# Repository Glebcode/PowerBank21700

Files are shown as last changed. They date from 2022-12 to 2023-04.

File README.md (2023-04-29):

# **Chunks PowerBank21700 DIY creation**
.stl for 3d printed power bank and manual for assembling all parts together.

**1.** Printed parts:
 
*-  bottomPartPowerBank21700.*

*-  topLidPartPowerBank21700.*

*-  bracketInsidePartPowerBank21700.*

*-  buttonPowerBank21700.*

**2.** 21700 batteries 6 pcs.

**3.** LED Dual USB 5V 2.4A Micro/Type-C USB Mobile Power Bank Charging Module.

**4.** Nickel stripe ≈ 35-40 cm.

**5.** Wire 22 awg ≈ 30cm.

**6.** Screws M1.6 х 6mm - 4pcs, М3 х 12mm – 4pcs.

**7.** Electrical isolation tape.

*More details, links and information you can find in **word files** in english, hebrew and ukrainian.<br> 
Hope you will enjoy it !*<br>
https://youtu.be/oLE26JI4mzE - short review video.

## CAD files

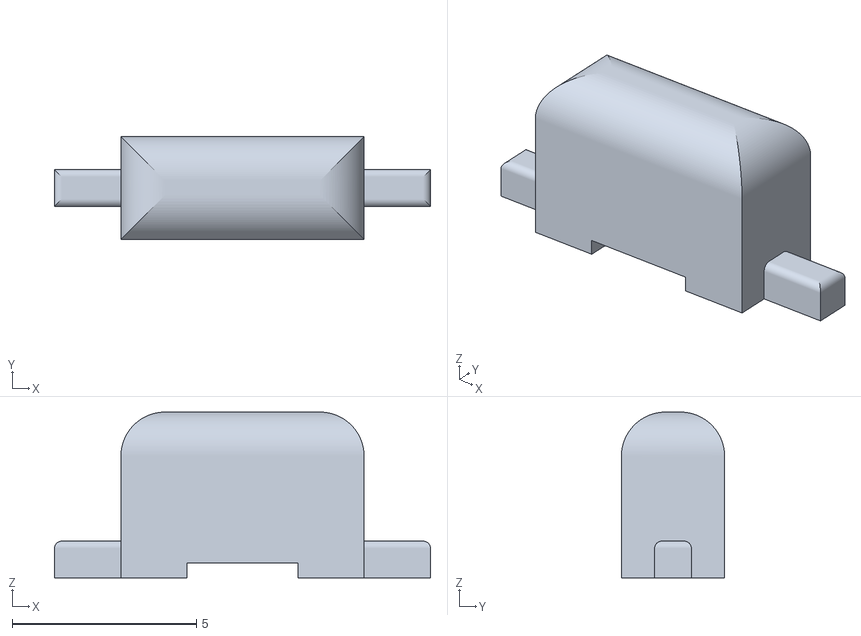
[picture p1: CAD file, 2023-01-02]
buttonPowerBank21700.stl
10.2 x 2.80 x 4.50

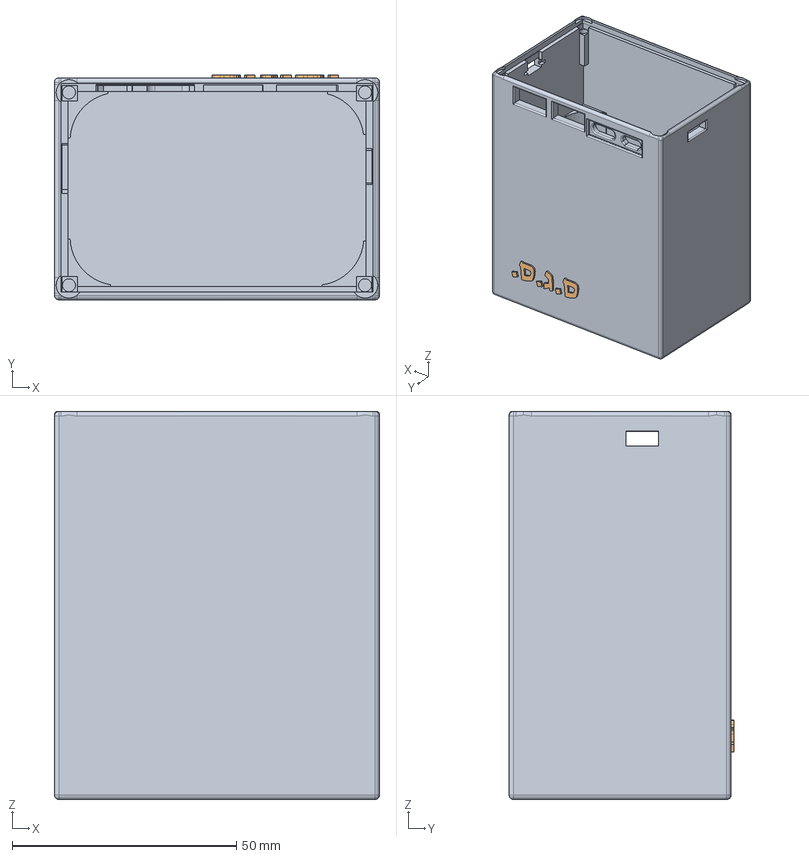
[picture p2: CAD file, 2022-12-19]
powerBank21700.FCStd
72.5 x 50.1 x 86.5 mm
hull
logo

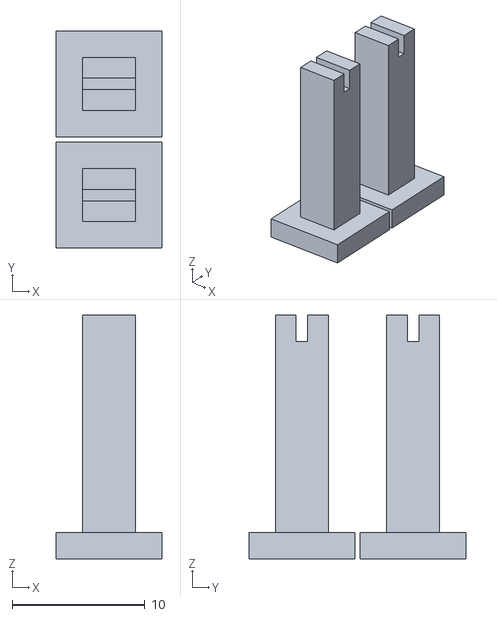
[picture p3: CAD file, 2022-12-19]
bracketInsidePartPowerBank21700.stl
8.00 x 16.4 x 18.4

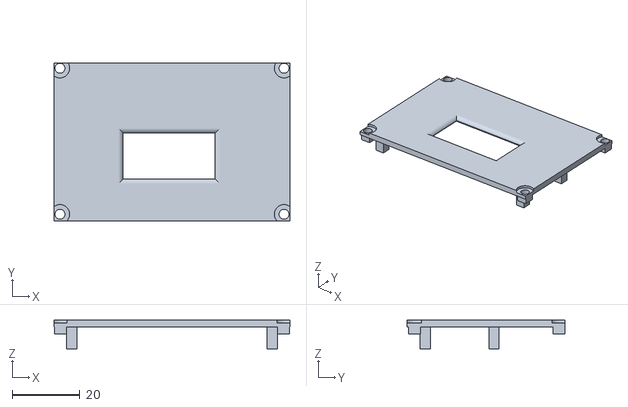
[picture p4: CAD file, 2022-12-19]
topLidPartPowerBank21700.stl
69.5 x 46.5 x 8.40

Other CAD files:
powerBank21700.stl

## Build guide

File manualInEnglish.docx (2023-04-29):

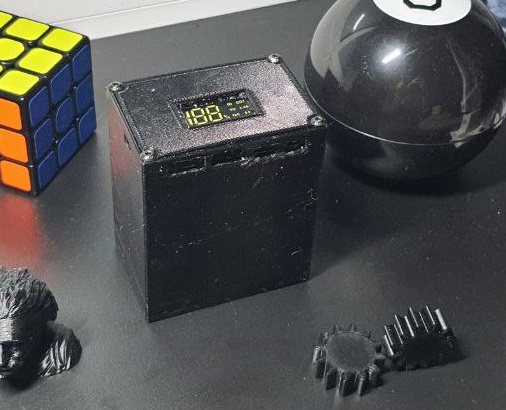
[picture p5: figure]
PB

Instructions how to assemble - Power Bank 6 elements 21700

Parts:

1. Printed parts:

a) bottomPartPowerBank21700.

b) topLidPartPowerBank21700.

c) bracketInsidePartPowerBank21700.

d) buttonPowerBank21700.

2. 21700 (any of), it is desirable to find 5000mAh.

I personally recommend these -(https://he.aliexpress.com/item/1005003484357179.html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).

3. LED Dual USB 5V 2.4A Micro/Type-C USB Mobile Power Bank Charging Module.

Link to the Power Module (which the .stl model of the case is made) -(https://he.aliexpress.com/item/1005004551965473.html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).

4. Nickel stripe ≈ 35-40cm.

5. Дріт електр. 22awg, один 15см, інший 10см.

(Which one will be shorter or longer depends on which pole you’ll land the elements to the bottom of the case).

6. Screws М1.6 х 6mm – 4pcs, М3 х 12mm – 4pcs.

7. Electrical isolation tape.

1. Necessary tool:

2. Soldering iron.

3. Spot welding for rechargeable batteries.

(It is possible without it and the nickel strip, but then there will be a greater probablem of the element being detached from the electrical circuit + it will be necessary to set new value of the length of the bottom part in the .stl file*1 in accordance with the thickness of the wires with which the battery will be soldered)

2. Screwdriver with bits.

3. Nippers or a knife.

( Work with the wires)

4. Sandpaper.

(Clean the place of connection of the wire with a nickel tape)

Procedure:

1. Connect the batteries using isol. tape

(maximum one layer to fit after into the case)

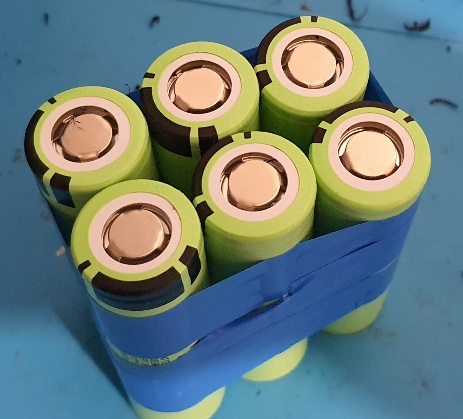
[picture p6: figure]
2fixedBatteries
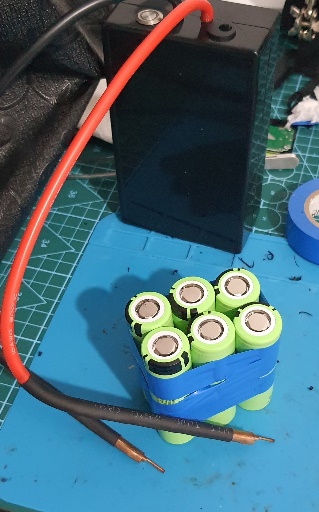
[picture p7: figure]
3spotWelding

2. We take spot welding

and nickel tape or

soldering iron and wires.

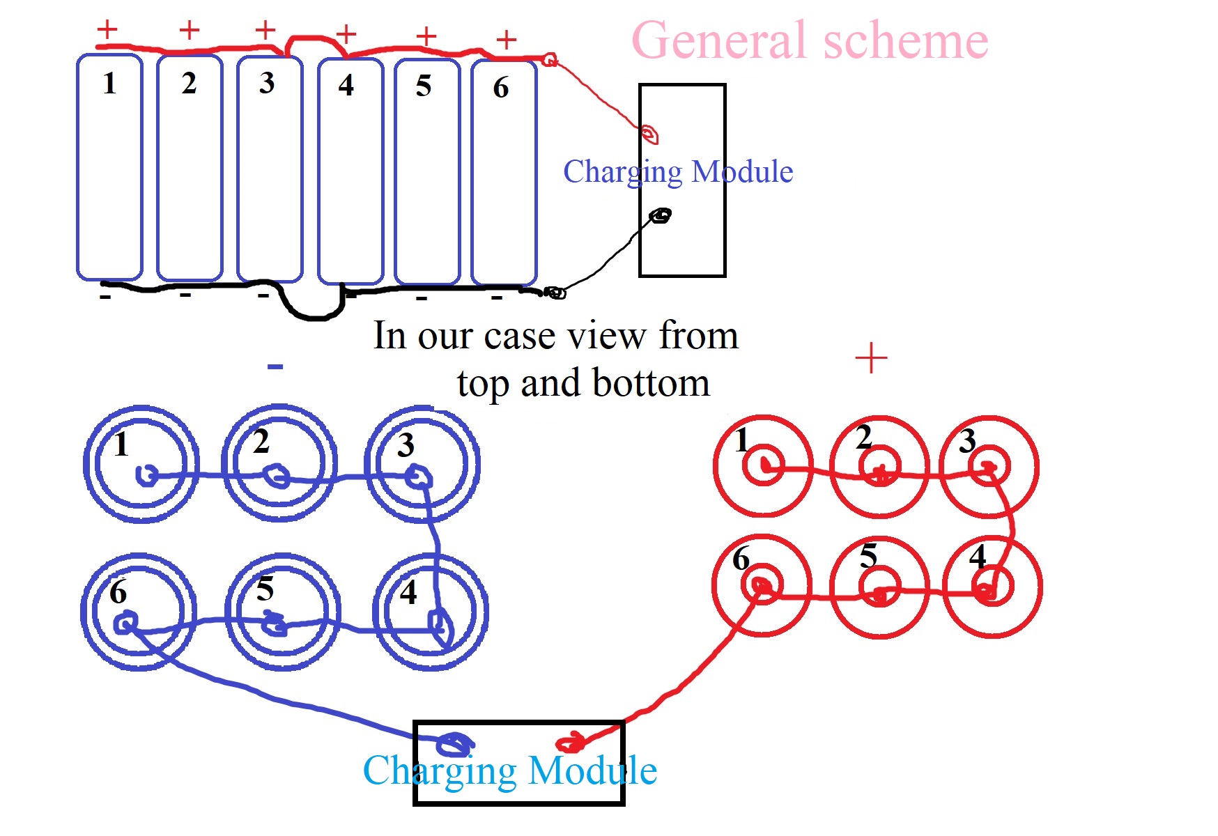
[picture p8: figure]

2.1. The scheme of connecting batteries to the charging module

(If it is clear, then we move to point 3).

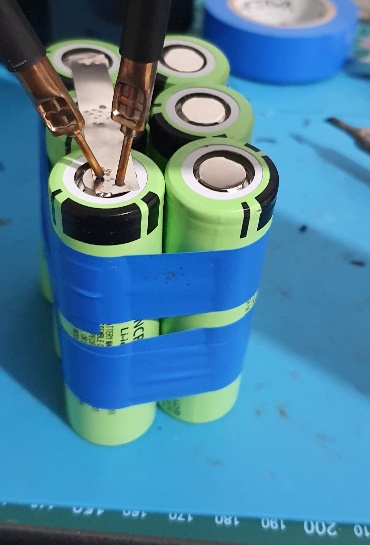
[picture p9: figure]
weldingBat

3. Solder according to scheme 2.1. our top/bottom variant.

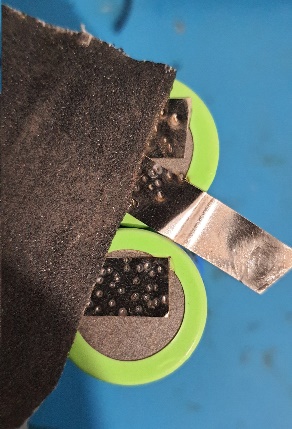
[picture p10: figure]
sandedGrdEnd
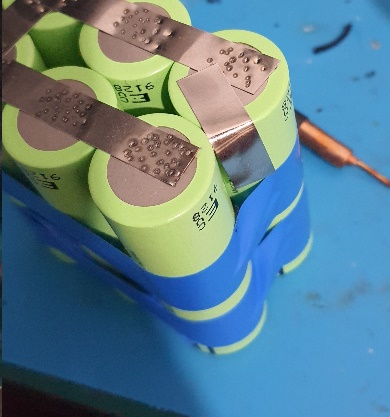
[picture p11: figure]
7grdEndWelding

4. We take a small one

3 cm piece of nickel stripe, we scraping one end with sandpaper (to apply solder wire, lead, it will be clear later) and weld the other (up to the 6th battery).

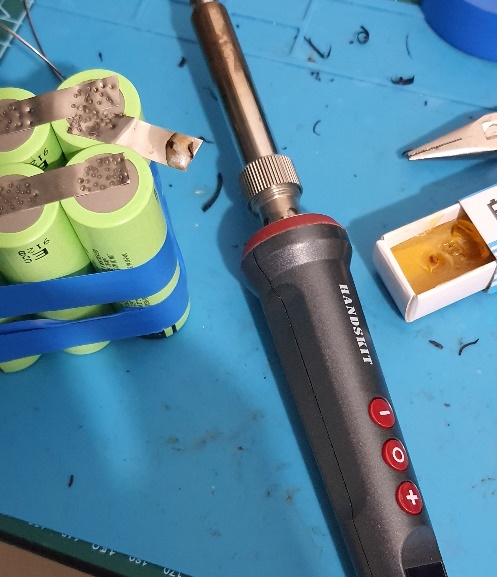
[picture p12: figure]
weldingWirePointGrd

5. Apply a drop of lead to the scraped area of the tape (it may fall off when it will be intensively in use. to increase adhesion).

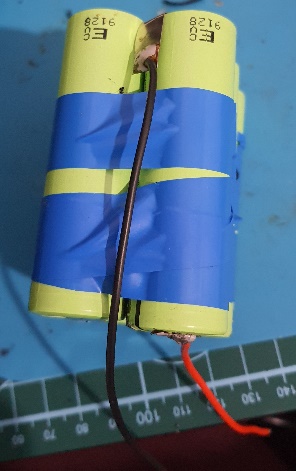
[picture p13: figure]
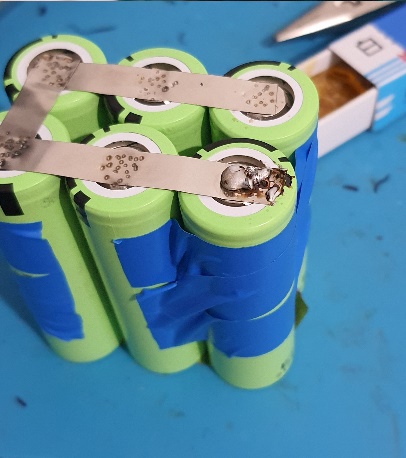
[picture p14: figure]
9weldingWirePoint3

5.1. We repeat the actions from points 4 and 5, but already for the other pole of the batteries (in the example, we first made the minus, now we move to the plus).

A small piece of nickel stripe, optional as it is needed for the bottom pole to push the 6 batteries together into the case. And for the wire from the bottom to place it between them without getting troubles with fitting the batteries into place.

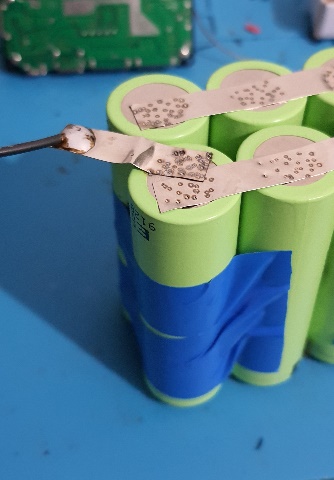
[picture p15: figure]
10wireGrd

7. We solder the negative wire (GND) 22awg, it is the lower part (in this case, you can, also, install the opposite side, there is no difference) Wire length of 15cm. (it is redundant for the further convenience of installing the cover).

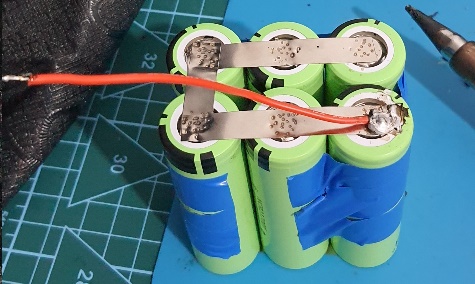
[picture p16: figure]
11wire3

8. Repeat point 7 with a 22awg-10cm wire for the 3.7v pole of the solder.

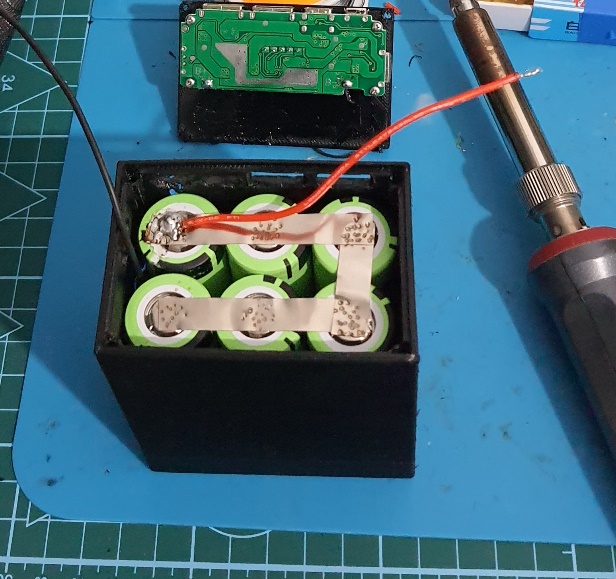
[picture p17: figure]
filledBottomPart

9. We insert the prepared batteries into the case (bottomPartPowerBank21700) (Attention! It is preferable to insert the positive wire in such a way that it is closer to the side where there are no USB holes, because, there may not be enough space for the charging module in the option shown in the photo).

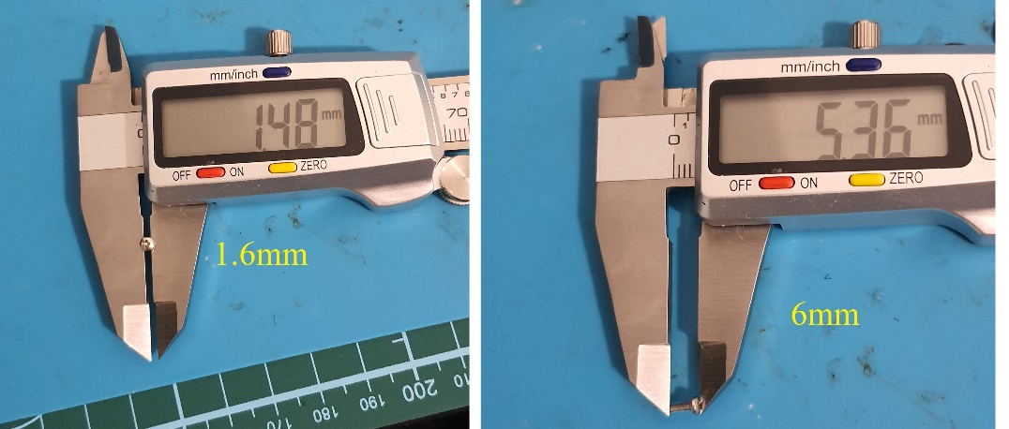
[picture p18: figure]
14screwsPowerModule
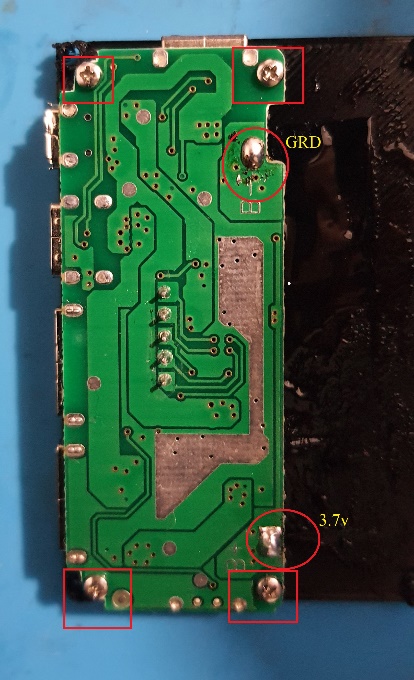
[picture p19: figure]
13powerModuleLidConnections

10. We screw the charging module to the cover (topLidPartPowerBank21700), M1.6 x 6mm bolts, apply lead drops to GRD and 3.7v (first read item 13.1.).

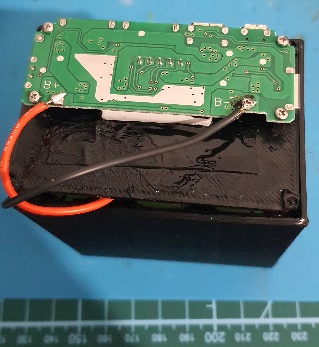
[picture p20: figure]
15solderedTopPartTo21700

11. We solder the workpiece to the charging module in accordance with the polarity.

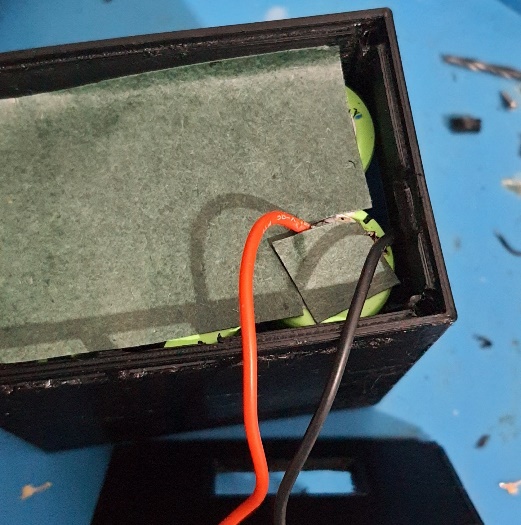
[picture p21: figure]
topPartIsolation

12. It is advisable*2 to stick a thin insulating material on top of the battery contacts to prevent short circuits.

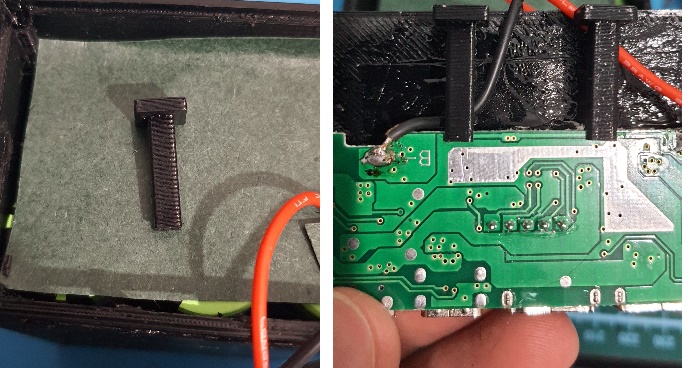
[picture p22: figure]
17bracketsInstallation

13. We install brackets*3 for support (bracketInsidePartPowerBank21700 ) in their place and the button (buttonPowerBank21700) is on the left side, when we are looking from the front at the USB holes.

13.1. Before screwing on the cover, if desired, treat the perimeter of the cover and all openings along the perimeter, including the hole for the screen, with a special agent*4 to prevent excess penetration of moisture and dust.

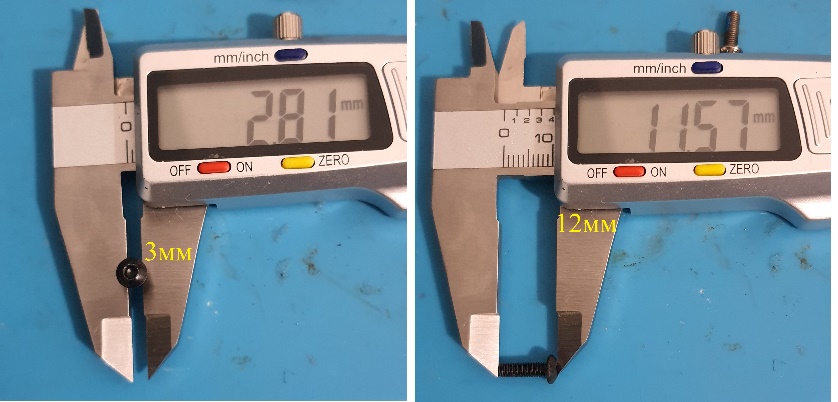
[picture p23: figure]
18lidScrews

14. We screw the cover (topLidPartPowerBank21700) to the body with M3 x 12mm bolts.

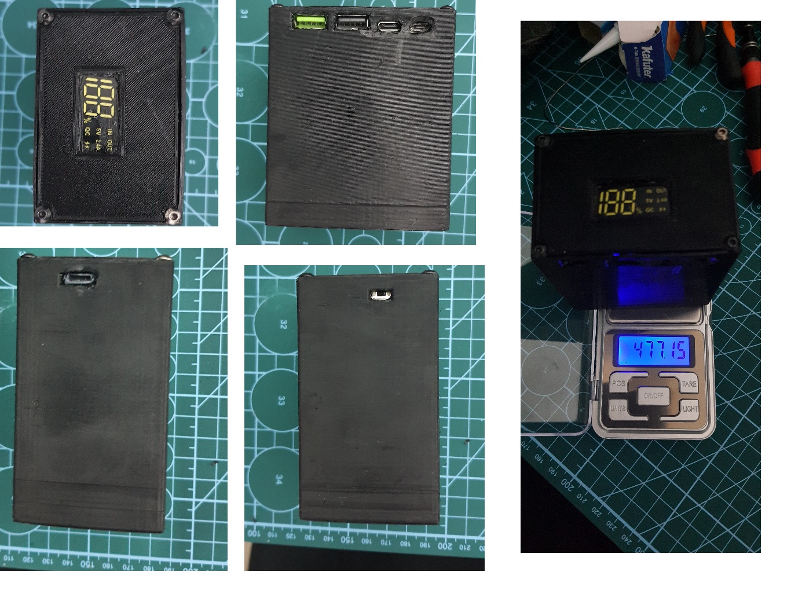
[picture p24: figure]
19exteriorLook

All the flaws in the sockets that are visible. In the .stl files have been eliminated (updated files), it was impossible to fit everything without a trial power bank.

The weight is almost 500 grams (it depends a lot on the batteries), if the elements are 5000 mAh each, then you get a 30000mAh power bank, which I think is not bad... The cost of production is much lower than buying a ready-made analogue. The main thing is high-quality 21700 batteries.

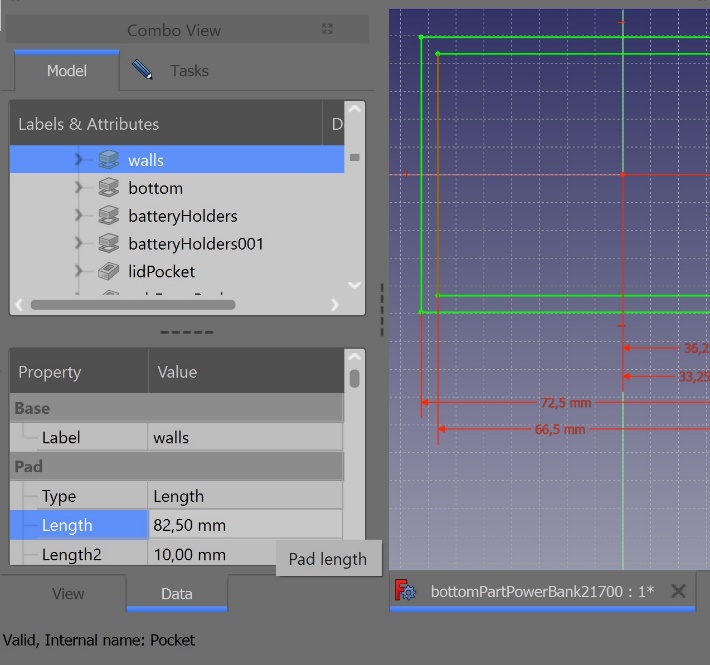
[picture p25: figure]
bottomHeight

*1- file - bottomPartPowerBank2170/walls – parameter length, increase by the thickness of the wires used for soldering.

*2- you can use insulating tape or special films (https://he.aliexpress.com/item/4000287488852.html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).

*3- during long-term operation, the charging module may fall inside, to prevent this, we install these supports.

*4- industrial silicone or special silicone for electronics (https://he.aliexpress.com/item/4000803938477.html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).

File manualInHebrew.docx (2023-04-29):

PB

הוראות הרכבה - סוללה נטענת 6 יח' 21700

רכיבים:

.1חלקים מודפסים:

.bottomPartPowerBank21700 א.

ב. topLidPartPowerBank21700.

ד. bracketInsidePartPowerBank21700.

ה. buttonPowerBank21700.

2. 21700 רצוי, למצוא 5000mAh.

אני אישית ממליץ על אלה - (https://he.aliexpress.com/item/1005003484357179.html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).

3. לוח טעינה v5 2.4A טעינה-פריקה.

קישור ללוח טעינה (שעבורו נוצר דגם ה-.stl של המארז) -( https://he.aliexpress.com/item/1005004551965473.html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).

4. פס ניקל ≈ 35-40 ס"מ.

5. חוט חשמלי 22awg, אחד 15 ס"מ, השני 10 ס"מ.

(איזה יהיה קצר יותר או ארוך יותר תלוי באיזה צד מורידים את הסוללות לתחתית המארז).

6. ברגים M1.6 x 6 מ"מ - 4 יח', M3 x 12 מ"מ - 4 יח'.

7. סרט בידוד.

כלי הכרחי:

1. מלחם.

2. ריתוך נקודתי לסוללות נטענות.

(אפשר בלעדיו ובלי פס הניקל בהתאם, אבל אז תהיה סבירות גדולה יותר לניתוק הסוללה מהמעגל החשמלי + יהיה צורך להוסיף את גובה המארז בקובץ .stl*1 בהתאם לחוטים שאיתם הסוללה תולחמה)

3. מברג עם ביטים.

(ביט לברגים)

4. צבת או סכין.

(לנקות את החוטים)

5. נייר זכוכית.

(נקה את מקום החיבור של החוט עם סרט ניקל)

תהליך:

3spotWelding
2fixedBatteries

1. חבר את הסוללות עם סרט הדבקה

מקסימום שכבה אחת שיהיה אפשרי להחניס למארז.

2. אנחנו לוקחים ריתוך נקודתי וסרט ניקל או

מלחם וחוטים.

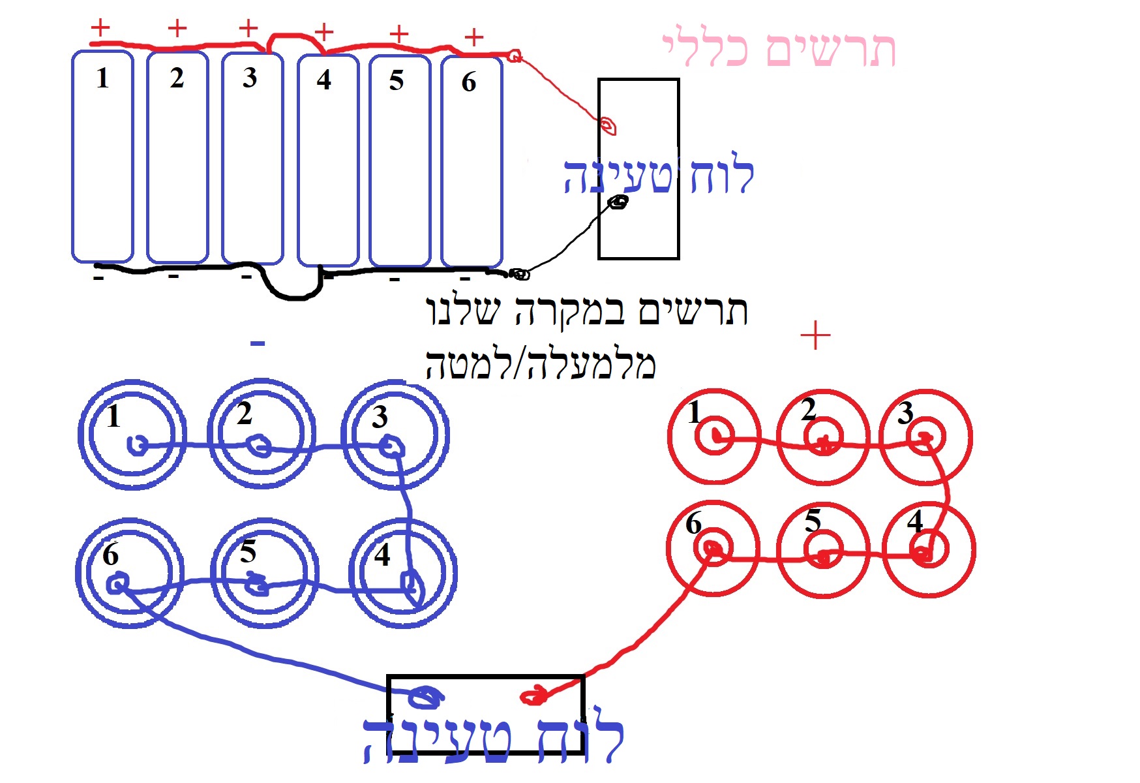
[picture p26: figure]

2.1. דיאגרמת חיבור הסוללה למודול הטעינה

(אם זה ברור, אז נעבור לנקודה 3).

weldingBat

3. הלחמה לפי סכמה 2.1. גירסה העליונה/תחתונה שלנו.

7grdEndWelding
sandedGrdEnd

4. אנחנו לוקחים חתיכת סרט ניקל בגודל 3 ס"מ, אנחנו מטפלים בקצה אחד בנייר זכוכית (כדי שיהיה יותר קל לחבר, זה יהיה ברור בהמשך) ומרתכים את השני (סוללה השישית).

weldingWirePointGrd

5. יש למרוח טיפת עופרת על האזור הנוקה של הסרט (מכיוון שהוא נוקה, הוא עלול ליפול במהלך השימוש, כדי להגביר את ההדבקה).

9weldingWirePoint3

5.1. אנו חוזרים על הפעולות מנקודות 4 ו-5, אבל כבר עבור הקוטב השני של הסוללות (בדוגמה הקודם עשינו את המינוס, עכשיו אנחנו עוברים לפלוס, חתיכת סרט ניקל קטנה , אופציונלי, מכיוון שהוא נחוץ כדי שהחלק התחתון ידחוף את 6 הסוללות יחד לתוך המארז וכדי שהחוט יעבור מלמטה ביניהן מבלי להפריע להכנסת הסוללות).

10wireGrd
11wire3

6. הלחמו את החוט השני 22awg מכיוון שהוא החלק לתחתון (במקרה הזה, ניתן להתקין אותו הפוך, אין הבדל), ואז האורך הוא 15 ס"מ. (זה מיותר לנוחות נוספת של התקנת הכיסוי).

חזור על נקודה 7 עם חוט awg22-10cm7. עבור הצד השני של קוטב הפלוס של ההלחמה.

filledBottomPart

8. אנו מכניסים את הסוללות המוכנות לתרמיל (bottomPartPowerBank21700) שימו לב! עדיף להכניס את החוט החיובי בצורה כזו שהוא קרוב יותר לצד שבו אין חורי USB שיהיה מספיק מקום אין מספיק מקום ללוח טעינה (להפך למה שמוצג בתמונה).

13powerModuleLidConnections

9. אנו מבריגים את לוח טעינה למכסה topLidPartPowerBank21700)) ברגים

M1.6 6 מ"מ, מורחים טיפות עופרת על GRD ו-3.7v (קריאה ראשונה בפריט 12.1.).

14screwsPowerModule
topPartIsolation
15solderedTopPartTo21700

10. אנו מלחמים את חומר העבודה ללוח טעינה בהתאם לקוטביות.

11. רצוי*2 להדביק חומר בידוד דק על גבי מגעי הסוללה למניעת קצרים.

17bracketsInstallation

12. אנו מתקינים סוגריים*3 לתמיכה bracketInsidePartPowerBank21700)) במקומם והלחצן buttonPowerBank21700)) נמצא בצד שמאל, כפי שניתן לראות מפני המכשיר איפה שחורי ה-USB.

12.1. לפני הברגת הכיסוי, אם רוצים, יש לטפל בהיקף הכיסוי ובכל הפתחים לאורך ההיקף, כולל החור למסך, בחומר מיוחד*4 למניעת חדירת יתר של לחות ואבק.

13. אנו מבריגים את המכסה topLidPartPowerBank21700)) למקומו עם ברגים M3 x 12 מ"מ.

18lidScrews
19exteriorLook

כל הפגמים בשקעים הנראים בקבצי ה-.stl בוטלו (קבצים מעודכנים), אי אפשר היה להתאים הכל ללא ניסיון.

המשקל הוא כמעט 500 גרם (תלוי הרבה בסוללות), אם הסוללות הם 5000 mAh כל אחד אז מקבלים סוללה נטענת של 30000mAh, שלדעתי לא רע... עלות הייצור הרבה יותר נמוכה מקנייה אנלוגי מוכן. העיקר הוא סוללות 21700 איכותיות, איכות שלהן.

bottomHeight

*1- קובץ bottomPartPowerBank2170/walls-length כפרמטר, הגדל אותו בהתאם לחוטים המשמשים

להלחמה.

*2- להשתמש בסרט בידוד או סרטים מיוחדים (https://he.aliexpress.com/item/4000287488852.html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).

*3- במהלך השימוש, לוח טעינה עלול ליפול פנימה, כדי למנוע זאת, אנו מתקינים תומכים אלה.

*4- סיליקון תעשייתי או סיליקון מיוחד לאלקטרוניקה (https://he.aliexpress.com/item/4000803938477.html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).

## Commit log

2022-12-16 powerBank21700 files pushing
    [bottomPartPowerBank21700.FCStd, bracketInsidePartPowerBank21700.FCStd, buttonPowerBank21700.FCStd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]
2022-12-18 middle part of power bank
    [powerBank21700.FCStd]
2022-12-19 .stl parts
    [bracketInsidePartPowerBank21700.stl, buttonPowerBank21700.stl, powerBank21700.stl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]
2022-12-19 if it will be necessary to set new length value
    In manual you will find additional information.
    [powerBank21700.FCStd]
2022-12-19 הסבר בעברית
2023-04-29 manuals
    manuals for assembling
